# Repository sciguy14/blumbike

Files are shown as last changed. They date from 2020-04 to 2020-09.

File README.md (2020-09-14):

# BLUM.BIKE
This repo contains the code and documentation related to my blum.bike IOT bike trainer project. My instance of this project is publically accessible at [blum.bike](https://blum.bike), but you can use this code to deploy your own implementation.
  
Copyright 2020 [Jeremy Blum](https://www.jeremyblum.com), [Blum Idea Labs, LLC.](https://www.blumidealabs.com)  
This project is licensed under the MIT license (see LICENSE.md for details).

## Current Features
* Workout session starts automatically when you start biking.
* Live speed, heatrate, and resistance are shown on the webapp during a session.
* Summary of the last ride is shown when not in a session.
* If being accessed the same public-facing IP that is broadcasting the data, controls will be shown allowing you to control the resistance during a session.
* Resistance can be dynamically controlled using a stepper motor coupled into the dyno-adjustment leadscrew.
* Heartrate is captured using a Polar heartrate chest strap.

## Repo Organization
* [blumbike_hardware](blumbike_hardware/): This folder includes the schematics, datasheets, and mechanical design files necessary for building the bike hardware.
* [blumbike_particle_firmware](blumbike_photon_firmware/): These are firmware files for flashing to the Particle Photon that powers the bike electronics.
* [blumbike_web_app](blumbike_web_app/): This the Python-based web app that is deployed to a Heroku Dyno.

## System Design
blum.bike has two main components: some cloud-connected simple electronics mounted to stationary bike, and a web app running on a Heroku free-tier dyno. They are connected via the Particle Cloud (a service the accompanies the Particle Photon microcontroller used in this project).

### Key Bike Hardware
* A road bike mounted on a stationary bike stand ([Amazon Link](https://amzn.to/3ezBoth)). A piece of black tape is added to the dyno. Its rotation in front of the optical sensor is used to compute dyno RPM.
* A [3D printed arm](blumbike_hardware/mechanical/breadboard_holder/) for mounting a full-length breadboard to the rear of the bike dyno. This part snaps in place, and is fixed in place with a hex standoff that inserts into one of the bolts on the Dyno.
* A full-length breadboard with the following main elements (see the full schematic in the [blumbike_hardware/schematics](blumbike_hardware/schematics/) folder and relevant datasheets in the [blumbike_hardware/datasheets](blumbike_hardware/datasheets/) folder).
    * A Particle Photon ([Documentation](https://docs.particle.io/datasheets/wi-fi/photon-datasheet)) cloud-connected microcontroller.
    * A QRD1114 optical sensor for measuring dyno RPM.
    * A comparator/hysteresis circuit based on an OPA344 Op-Amp for cleaning up the RPM measurement.
    * A Polar wireless heart rate receiver. This is attached via a wire harness to put it close to the bike seat.
    * A Polar T34 Chest strap heart rate sensor ([Amazon Link](https://amzn.to/2RPv1s9)).
    * A Trinamic TMC2209 Stepper Driver breakout board for driving a stepper motor that adjusts dyno resistance ([Amazon Link](https://amzn.to/2YsIutj))
    * A L7805 Linear 5V regulator (plus bulk decoupling caps) for powering the logic elements from the 12V AC/DC wall adapter (12V is used for the Stepper Motor supply).
* A 12V, 1.5A AC/DC Wall adapter
* A NEMA-17 Stepper motor with a Planetary Gearbox ([Amazon Link](https://amzn.to/3emq3wr)) and 3D-printed adapter for controlling dyno resistance
* An endstop switch clipped onto the adjustable dyno with a 3D-printed bracket (so the stepper motor can home its resistance)

### Photon Firmware and Cloud
The Particle Photon runs some simple firmware that determines session start/stop time, heart rate, bike speed, etc. It publishes all the relevant data to the particle cloud once per second. The particle cloud is configred to fire a webhook to the python web app each time an update is received. A secret API key is inserted into the webhook contents, which is validated by the receiving web app.

### Python Web App Implementation
The web app is built as a python virtual env. It uses [Plotly Dash](https://dash.plotly.com/introduction) as the main mechanism for the UI and the graphs. It is deployed onto a [Heroku Free-Tier Dyno](https://www.heroku.com/pricing) and it leverages a [Heroku redis](https://elements.heroku.com/addons/heroku-redis) resource to maintain data for the duration of a session. To secure communication between the Particle cloud and the Heroku server, a matching API key is generated and stored in a Heroku environment variable for validating that the incoming webhook data from the Particle cloud is authentic. [Dash Bootstrap Components](https://dash-bootstrap-components.opensource.faculty.ai/) are used for the styling of the front-end.

## Instructions
This section is still a work in progress as I am still developing this project.
1. Fork this Repo to your own gitHub account and modify it as you desire.
2. 3D Print and assemble the mechanical elements. Build the circuit as described by the schematic. You will probably need to use a scope or a logic analyzer to get the alignment of the optical sensor working properly to generate consistent pulses on each dyno rotation.
3. Associate the Particle Photon to your Wi-Fi network and to your Particle Cloud account.
4. Use the Particle Dev IDE to flash the firmware onto the Photon via the cloud, or copy the firmware into their cloud IDE and flash it from there. Ensure that you see events streaming into the Particle Cloud interface for your device.
5. On the Particle Cloud Integration page, setup a new Webhook. Choose to create a custom template and populate it as follows (replacing the <> items accordingly):
    ```JSON
    {
        "event": "bike_data",
        "deviceID": "<YOUR_DEVICE_ID>",
        "url": "https://<YOUR_HEROKU_URL>/update",
        "requestType": "POST",
        "noDefaults": true,
        "rejectUnauthorized": true,
        "json": {
            "event": "{{{PARTICLE_EVENT_NAME}}}",
            "data": "{{{PARTICLE_EVENT_VALUE}}}",
            "apikey": "<YOUR_RANDOMLY_GENERATED_API_KEY>"
        }
    }
    ```  
    The API key can be whatever you want. You will just need to use the same key when you setup the heroku environment variables. We use this in the webapp to ensure that we only process incoming data with this secret API key attached.
6. Now, you need to create an access token associated with your particle.io account that can be used to sent authenicated commands to your particle photon. Install the [Particle Cli](https://docs.particle.io/tutorials/developer-tools/cli/)
7. Once the cli is installed launch your terminal and run `particle setup` to login, and then run `particle token create --never-expires`. This will add a token to your account that can be used the authenticate the app. The token will be printed to the console. Copy it somewhere for use in later steps.
8. Create a Heroku Account, and spin up a free-tier dyno.
9. Choose to "Deploy from GitHub" and connect it to your GitHub account. Point it at the repo that you forked to your account.
10. On the "Settings" page for the dyno, add the following "Config Vars":  
    `apikey` = `<YOUR_RANDOMLY_GENERATED_API_KEY>` - this is the same API key you configured in the JSON webhook above.  
    `PROJECT_PATH` = `blumbike_web_app` - this will make the Heroku automatic GitHub deployment look in the right subfolder of this repo for the application ([more info about this](https://stackoverflow.com/a/53221996)).  
    `SECRET_KEY` = `<ANY_RANDOM_KEY_YOU WANT>` - this is used for session management in the app. It is sepeerate from your api key and your access token.  
    `PARTICLE_TOKEN` = `<THE_PARTICLE_TOKEN_YOU_GENERATED_IN_THE_PARTICLE_CLI>` - this is the access token you generated above. The particle cloud will only approve the apps control request if this matches an allowed token.  
    `PARTICLE_ID` = <`THE_UNIQUE_ID_FOR_YOUR_PARTICLE`> - get this from the particle web console. It will match this format: `0123456789abcdef01234567` (24 hex digits)
11. Add a buildpack that will ensure the right subdirectory is used for automatic deployment. Add https://github.com/timanovsky/subdir-heroku-buildpack.git to the buildpack list and drag it to the top of the list (above python).
12. On the "Resources" page for your Dyno add a Heroku Redis instance. This should automatically add a "Config Var" with your `REDIS_URL`. This app will use this redis store to hold your data.
13. On the "Deploy" page, choose to deploy your master branch. Future deploys will happen automatically each time you push local changes to your upstream master branch.

## Doing Local Development
It's impractical to re-deploy to Heroku for every software change that you want to test. I recommend the following local development environment:  
I like using [PyCharm](https://www.jetbrains.com/pycharm/) for development of the Python web app, and I used [Particle Dev](https://docs.particle.io/tutorials/developer-tools/dev/) to write and deploy firmware to the Particle Photon.
  
[Ngrok](https://ngrok.com/) can be used to pipe the Photon webhooks to the localhost development server that you'll be running on your local machine. Create an account, and install it on your development machine. Once installed, launch the service with `ngrok http 8050`. This will give you a forwarding URL of the format `https://<UNIQUE ID>.ngrok.io`. You can also see this URL in your ngrok dashboard at [dashboard.ngrok.com](https://dashboard.ngrok.com/status/tunnels). Temporarily edit your Particle webhook event to use this URL instead of the heroku URL. So for example, you would cheange `https://my-app.herokuapp.com/update` to `https://abcde12345.ngrok.io/update`. You should be able to see the webhook requests come into this termainal window as soon as you point the Particle webhook at this address. You will see "502 Bad Gateway Errors" until you actually launch your local development server from PyCharm.
  
Create a new PyCharm project in the `blumbike_web_app` folder. Set up the Virtual Env using the requirements.txt file (PyCharm should prompt you to install the right things). Create a Run configuration pointed at app.py and using the Virtual Env interpreter. Add the following environment variables ([instructions](https://stackoverflow.com/questions/42708389/how-to-set-environment-variables-in-pycharm/42708480#42708480)):
* `mode` = `dev` - This will configure the server to run on local port 8050, which is what you used to setup ngrok.
* `apikey` = `<PUT_YOUR_API_KEY_HERE>` - This is the same apikey that you added to the particle webhook JSON message and to heroku.
* `REDIS_URL` = `<PUT_YOUR_REDIS_URL_HERE>` - You can use the same REDIS URL that is used by Heroku, or you can run a seperate development redis instance on your local machine and point at that.
* `SECRET_KEY` = `<PUT_YOUR_SECRET_KEY_HERE>` - This is the same secret key that you entered in heroku.
* `PARTICLE_TOKEN` = `<PUT_YOUR_PARTICLE_TOKEN_HERE>` - This is the same particle token, retrieved from the particle cli, that you added to the heroku env vars.
* `PARTICLE_ID` = <`THE_UNIQUE_ID_FOR_YOUR_PARTICLE`> - get this from the particle web console. It will match this format: `0123456789abcdef01234567` (24 hex digits)
  
Run the PyCharm configuration that you setup, and the ngrok instance should start showing "200 OK" responses. Visit [localhost:8050/](http://localhost:8050/) in your webbrowser to see your local instance of the web app. You can see more details about the webhooks coming into your machine via the ngrok inspection interface at [localhost:4040/inspect/http](localhost:4040/inspect/http).

## Other Useful References
The following are some use websites that I referenced while working on this project. You might find them useful as well:
* [Curing Comparator Instability with Hysteresis](https://www.analog.com/en/analog-dialogue/articles/curing-comparator-instability-with-hysteresis.html#)
* [Inverting Schmitt Trigger Calculator](https://www.random-science-tools.com/electronics/inverting-schmitt-trigger-calculator.htm)
* [Using an Op-amp as a Comparator](https://www.electronics-tutorials.ws/opamp/op-amp-comparator.html)
* [QRD1114 Optical Detector Hookup Guide](https://learn.sparkfun.com/tutorials/qrd1114-optical-detector-hookup-guide/all)
* [Particle Photon API Reference](https://docs.particle.io/reference/device-os/firmware/photon/#cloud-functions)
* [Plotly Dash Documentation](https://dash.plotly.com/dash-core-components)

_Disclaimers: As an Amazon Associate, I earn from qualifying purchases if you purchase items via Amazon.com links in this README. I also assume no liability if you manage to injure yourself while using a stationary bike._

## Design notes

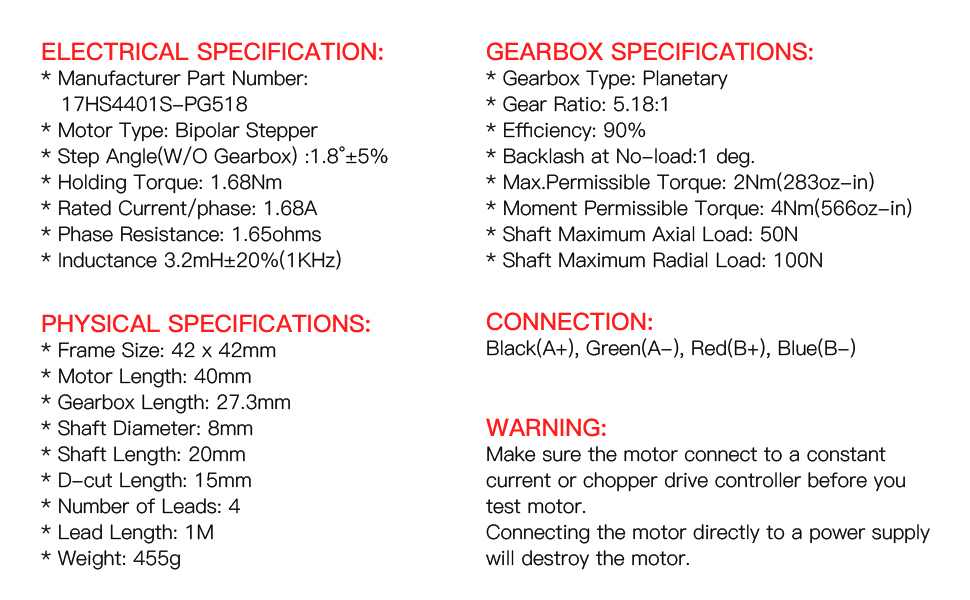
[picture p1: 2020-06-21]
blumbike_hardware/datasheets/Stepper-Motor_Specs.jpg

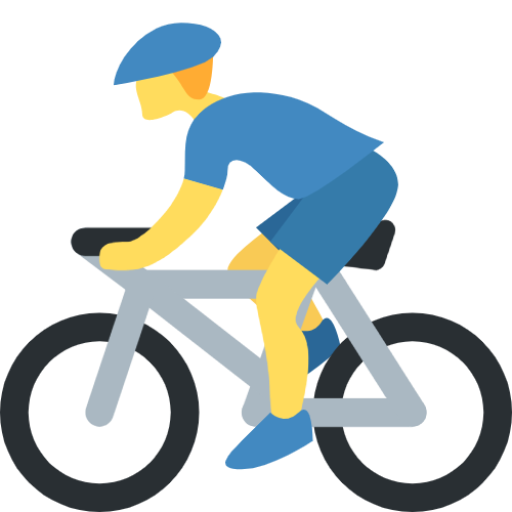
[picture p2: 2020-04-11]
blumbike_web_app/assets/android-chrome-512x512.png

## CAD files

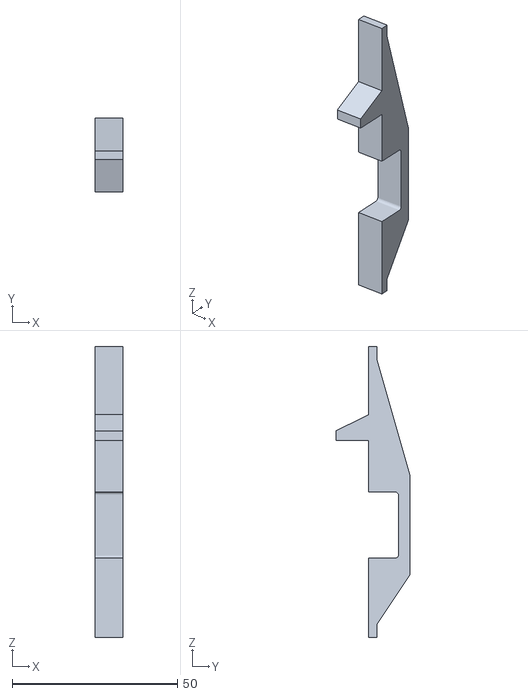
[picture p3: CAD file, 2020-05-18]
blumbike_hardware/mechanical/breadboard_holder/top_clip.stl
8.50 x 22.4 x 88.0

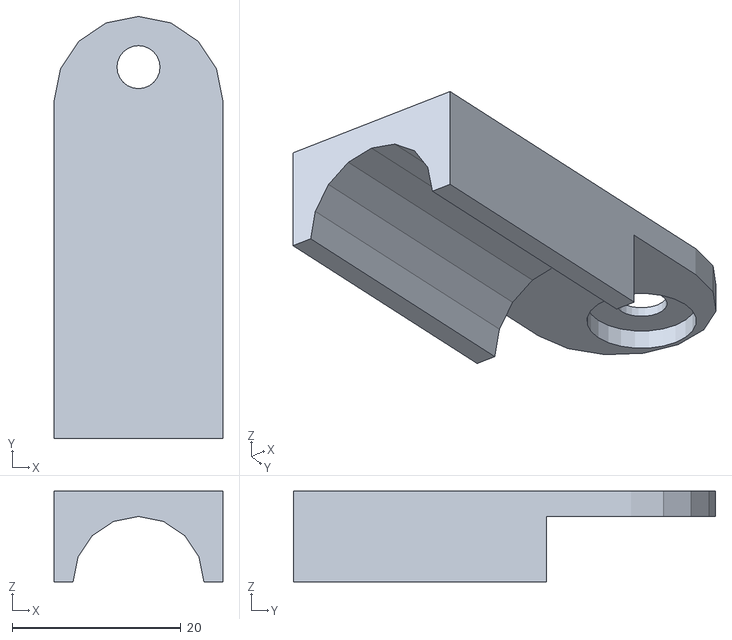
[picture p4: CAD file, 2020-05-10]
blumbike_hardware/mechanical/heartrate_sensor_holder/heartrate_sensor_holder.stl
20.0 x 50.0 x 10.7

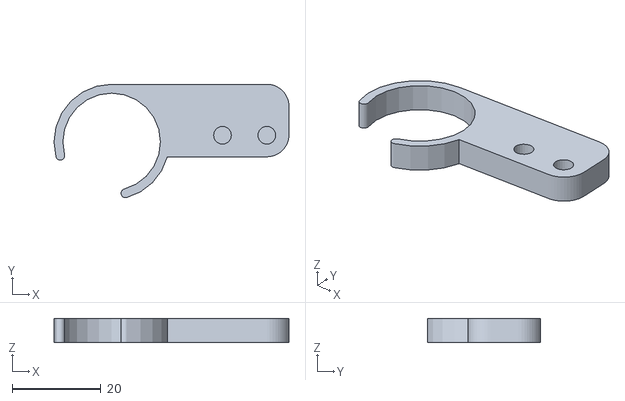
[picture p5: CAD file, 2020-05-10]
blumbike_hardware/mechanical/resistance_limit_switch_holder/resistance_limit_switch_holder.stl
53.0 x 25.6 x 5.50

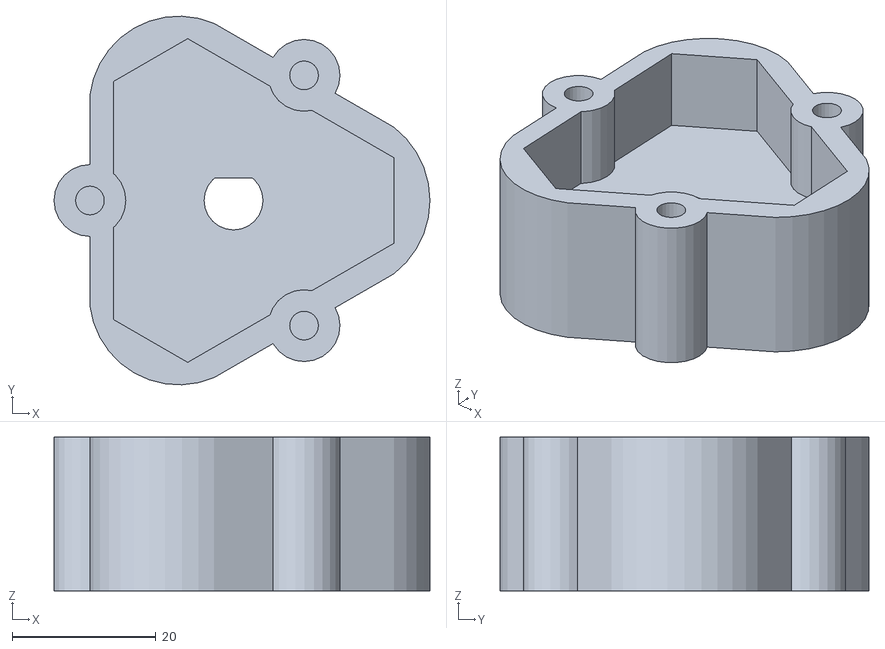
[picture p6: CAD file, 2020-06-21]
blumbike_hardware/mechanical/stepper_adapter/stepper_adapter_body.stl
52.4 x 51.3 x 21.4

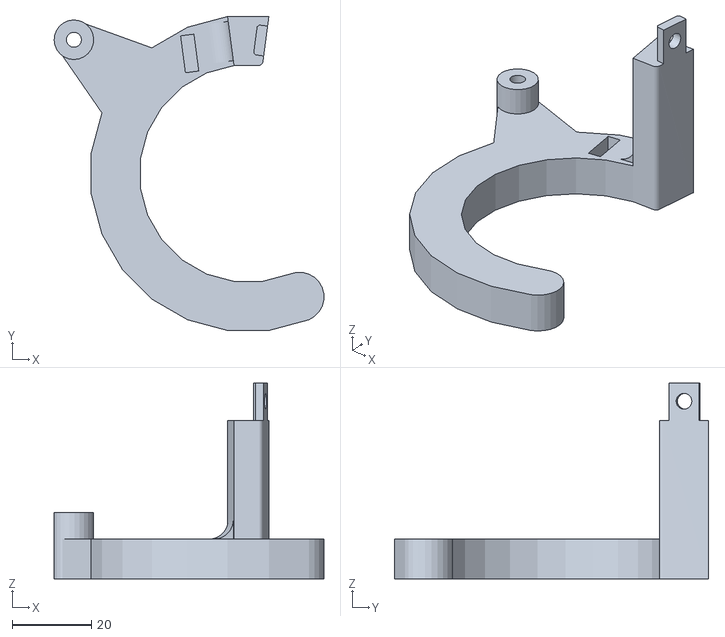
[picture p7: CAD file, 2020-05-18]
blumbike_hardware/mechanical/breadboard_holder/bottom_clip_right.stl
68.1 x 79.3 x 49.4

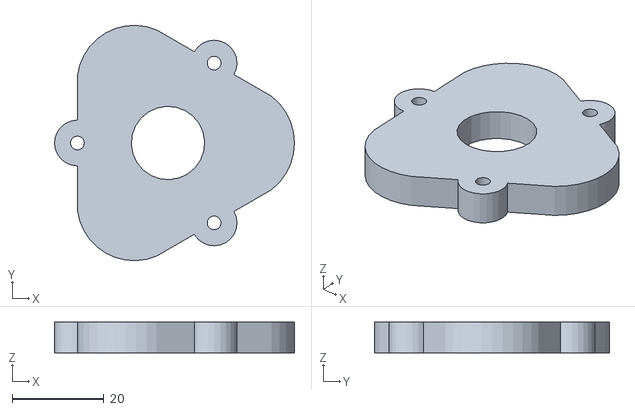
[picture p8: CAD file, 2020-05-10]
blumbike_hardware/mechanical/stepper_adapter/stepper_adapter_lid.stl
52.4 x 51.3 x 6.70

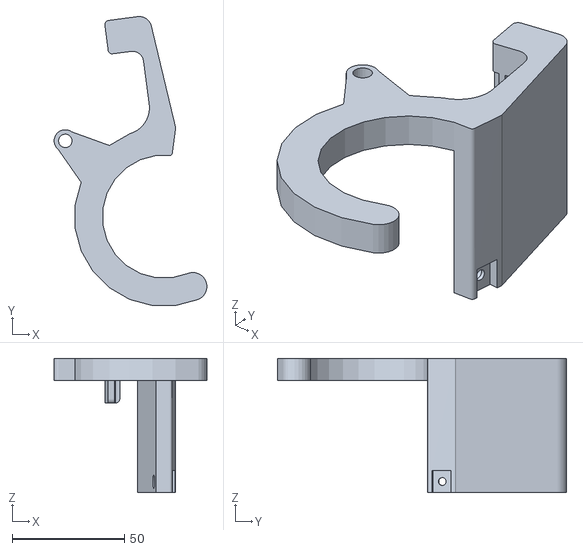
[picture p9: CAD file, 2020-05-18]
blumbike_hardware/mechanical/breadboard_holder/bottom_clip_left.stl
68.1 x 128.9 x 60.0

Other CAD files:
blumbike_hardware/mechanical/breadboard_holder/breadboard_holder.skp
blumbike_hardware/mechanical/heartrate_sensor_holder/heartrate_sensor_holder.skp
blumbike_hardware/mechanical/resistance_limit_switch_holder/resistance_limit_switch_holder.skp
blumbike_hardware/mechanical/stepper_adapter/stepper_adapter.skp

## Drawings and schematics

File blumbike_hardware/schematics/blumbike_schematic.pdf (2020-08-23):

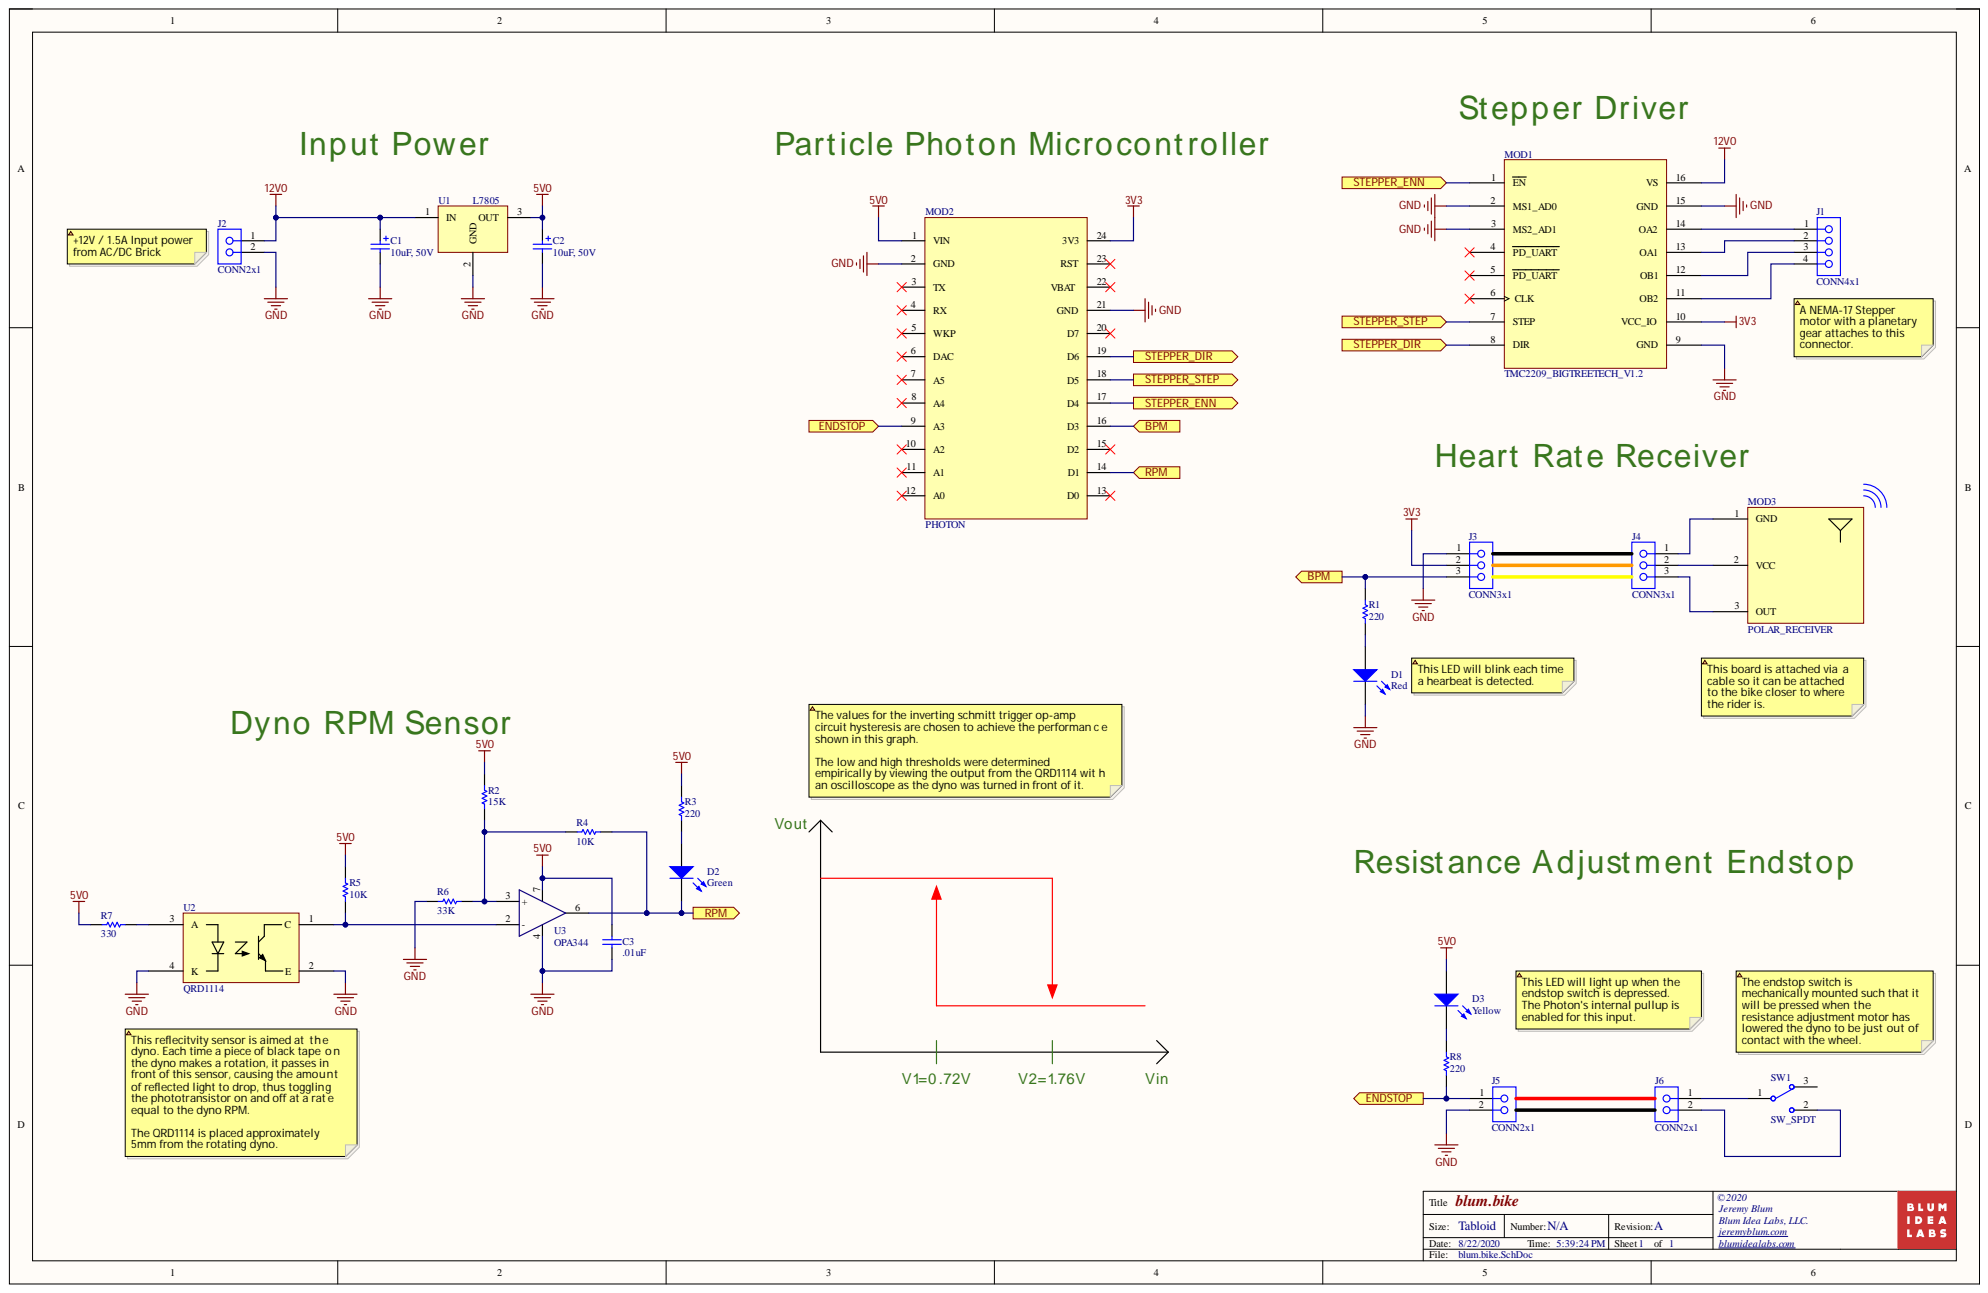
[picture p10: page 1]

+12V / 1.5A Input power from AC/DC Brick

A NEMA-17 Stepper
motor with a planetary gear attaches to this

GND 1

VCC 2

This LED will blink each time a hearbeat is detected.

This board is attached via a cable so it can be attached to the bike closer to where

The values for the inverting schmitt trigger op-amp circuit hysteresis are chosen to achieve the performance

shown in this graph.

The low and high thresholds were determined empirically by viewing the output from the QRD1114 with

an oscilloscope as the dyno was turned in front of it.

This LED will light up when the endstop switch is depressed.

The endstop switch is mechanically mounted such that it

The Photon's internal pullup is
enabled for this input.

will be pressed when the
resistance adjustment motor has lowered the dyno to be just out of contact with the wheel.

This reflecitvity sensor is aimed at the dyno. Each time a piece of black tape on

the dyno makes a rotation, it passes in front of this sensor, causing the amount

of reflected light to drop, thus toggling
the phototransistor on and off at a rate equal to the dyno RPM.

The QRD1114 is placed approximately 5mm from the rotating dyno.

blum.bike Title | © 2020 Jeremy Blum Blum Idea Labs, LLC. jeremyblum.com

Size: Tabloid | Number: N/A | Revision: A

Date: 8/22/2020 Time: 5:39:24 PM | | Sheet 1 of 1 | blumidealabs.com

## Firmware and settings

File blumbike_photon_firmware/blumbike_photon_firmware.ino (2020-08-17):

// blum.bike Photon Firmware
// Copyright 2020 Jeremy Blum, Blum Idea Labs, LLC.
// www.jeremyblum.com
// This code is licensed under MIT license (see LICENSE.md for details)

// Includes
#include "math.h"

// Define compiler replacements for Stepper motor direction
#define HIGHER_RESISTANCE LOW
#define LOWER_RESISTANCE HIGH

// Define compiler replacements for endstop start_session
#define PRESSED LOW
#define UNPRESSED HIGH

// Define Pin Constants
const int ENDSTOP_PIN       = A3; // The switch that triggers when the resistance adjuster stepper is at the end of its range
const int RPM_PIN           = D1; // The output of the inverting comparator w/ hysteresis for measuring bike speed
const int BPM_PIN           = D3; // The output pulses from the Heart rate BPM Polar receiver
const int ONBOARD_LED_PIN   = D7; // The onboard blue LED
const int STEPPER_ENN       = D4; // TMC2209 Stepper Driver Enable Pin (Active Low)
const int STEPPER_STEP      = D5; // TMC2209 Stepper Driver Step Pin
const int STEPPER_DIR       = D6; // TMC2209 Stepper Driver Direction Pin

// Configuration Constants
const unsigned int UPDATE_RATE_MS                               = 1000; // Update and send the new values every 1000 milliseconds (this should not be any lower than 1000)
const unsigned int BPM_INTERRUPTED_THRESHOLD                    = 2000; // If more than this many milliseconds have elapsed since the last BPM trigger, presume the sensor is not transmitting
const unsigned int SESSION_STARTED_SEQUENTIAL_NON_ZERO_READINGS = 2;    // A new session is triggered when this many non-zero RPM readings are found in a row
const unsigned int SESSION_ENDED_SEQUENTIAL_ZERO_READINGS       = 6;    // A session is ended when this many zero RPM readings are found in a row
const double RPM_MOVEMENT_THRESHOLD                             = 1.0;  // To address floating point errors, set this value as the movement threshold. Anything below this is effectively "zero" movement
const double ZERO_RESISTANCE_TURNS                              = 2.75; // The number of full output shaft turns the stepper motor must do to achieve the minimum resistance setting (just barely touching the wheel)
const double ROTATIONS_PER_RESISTANCE_STEP                      = 0.25; // Every 1/4th turn of the stepper motor output shaft is equal to one "resistance step"
const unsigned int DEFAULT_RESISTANCE                           = 3;    // This is the default starting session resistance
const unsigned int MAX_RESISTANCE                               = 10;   // This is the maximum resistance setting
const unsigned int MIN_RESISTANCE                               = 1;    // This is the minimum resistance setting

// Define Math Constants
const double BIKE_WHEEL_DIAMETER    = 27.0;            // inches
const double DYNO_WHEEL_DIAMETER    = 1.80;            // inches
const double PI                     = 3.14159265359;   // ratio
const double FEET_PER_MILE          = 5280.0;          // ratio
const double INCHES_PER_FOOT        = 12.0;            // ratio
const double MINUTES_PER_HOUR       = 60.0;            // ratio
const double SECONDS_PER_MINUTE     = 60.0;            // ratio
const double MILLIS_PER_SECOND      = 1000.0;          // ratio
const double STEPS_PER_REV_NO_GEAR  = 200.0;           // The NEMA-17 Stepper motor has 200 steps/rev
const double MICROSTEPPING          = 8.0;             // MS1 and MS2 are pulled down by default putting us in 1/8 Microstepping mode
const double GEAR_RATIO             = 5.18;            // The planetary gearbox for the motor is 5.18:1

// Computed Constants
const double BIKE_WHEEL_CIRCUMFERENCE_INCHES       = PI * BIKE_WHEEL_DIAMETER;                                          // inches
const double BIKE_WHEEL_CIRCUMFERENCE_FEET         = BIKE_WHEEL_CIRCUMFERENCE_INCHES / INCHES_PER_FOOT;                 // feet
const double BIKE_WHEEL_REVOLUTIONS_PER_MILE       = FEET_PER_MILE / BIKE_WHEEL_CIRCUMFERENCE_FEET;                     // revs / mile
const double DYNO_WHEEL_CIRCUMFERENCE_INCHES       = PI * DYNO_WHEEL_DIAMETER;                                          // inches
const double BIKE_DYNO_CIRCUMFERENCE_RATIO         = BIKE_WHEEL_CIRCUMFERENCE_INCHES / DYNO_WHEEL_CIRCUMFERENCE_INCHES; // rpm multiplier
const double STEPS_PER_REV                         = STEPS_PER_REV_NO_GEAR * GEAR_RATIO * MICROSTEPPING;                // The actual number of step pulses to go a full rotation of the output shaft

// Define Cloud Functions
int resistanceUp(String na);
int resistanceDown(String na);

// Global Variables
char ip[128];
bool in_session = false;
unsigned long resistance = 0;
unsigned long sequential_non_zero_readings = 0;
unsigned long sequential_zero_readings = 0;
unsigned long timestamp_seconds = 0;
double dyno_rpm = 0.0;
double bike_rpm = 0.0;
double bike_mph = 0.0;
double heart_bpm = 0.0;
unsigned long last_rpm_time = 0;
volatile unsigned long revs = 0;
volatile unsigned long last_beat_time = 0;
volatile unsigned long beat_time = 0;
volatile double interrupt_bpm = 0.0;

void setup(){
    // register the cloud functions
    Particle.function("resistance_up", resistanceUp);
    Particle.function("resistance_down", resistanceDown);

    // Set Pin Directions/Modes
    pinMode(ENDSTOP_PIN, INPUT_PULLUP);
    pinMode(RPM_PIN, INPUT);
    pinMode(BPM_PIN, INPUT);
    pinMode(ONBOARD_LED_PIN, OUTPUT);
    pinMode(STEPPER_ENN, OUTPUT);
    pinMode(STEPPER_STEP, OUTPUT);
    pinMode(STEPPER_DIR, OUTPUT);
    digitalWrite(STEPPER_ENN, HIGH);
    digitalWrite(ONBOARD_LED_PIN, LOW);

    // Get our Public IP address
    // On the Web-app we only allow resistance control if the request originates from the same IP
    Particle.subscribe("particle/device/ip", ip_handler, MY_DEVICES);
    Particle.publish("particle/device/ip", PRIVATE);

    // Home the Resistance Stepper
    homeStepper();

    // Adjust the stepper such that the resistance is set to the default starting level
    adjustResistanceAbsolute(DEFAULT_RESISTANCE);

    // Cloud Variables - We don't need these, since we publish the values every second, but it's still useful to have them
    Particle.variable("in_session", in_session);
    Particle.variable("resistance", resistance);
    Particle.variable("dyno_rpm", dyno_rpm);
    Particle.variable("bike_rpm", bike_rpm);
    Particle.variable("bike_mph", bike_mph);
    Particle.variable("heart_bpm", heart_bpm);

    // Notify the cloud that the bike has been turned on
    timestamp_seconds = Time.now(); // Get the current time
    String msg = "{\"t\": " + String(timestamp_seconds) + ", \"event\": \"powered_on\"}";
    Particle.publish("bike_data", msg, PRIVATE | WITH_ACK);

    // Initialize the last time values to something correct so it is ready for first use
    last_rpm_time = millis();
    last_beat_time = millis();

    // Attach pin change interrupts
    attachInterrupt(RPM_PIN, rpmInterrupt, FALLING);
    attachInterrupt(BPM_PIN, bpmInterrupt, RISING);
}

void loop() {
    // Update at the requested update rate
    // leverage some of this time to keep the update pulse LED on long enough to see
    delay(200);
    digitalWrite(ONBOARD_LED_PIN, LOW);
    delay(UPDATE_RATE_MS-200);

    // Get the current time
    timestamp_seconds = Time.now();

    // Disable interrupts while we process volatile data
    noInterrupts();

    // RPM tracking
    dyno_rpm =  SECONDS_PER_MINUTE*double(UPDATE_RATE_MS)/double(millis() - last_rpm_time)*double(revs); // Compute the RPMs of the Dyno
    last_rpm_time = millis(); // Reset the rpm clock
    revs = 0; // Reset the rpm counter

    //Manage the condition where heartrate is zero
    if (millis() - last_beat_time > BPM_INTERRUPTED_THRESHOLD) {
        heart_bpm = 0.0;
    } else {
        // Set Heartrate equal to he value of the volatile variable computed in the interrupt
        heart_bpm = interrupt_bpm;
    }

    // Interrupts can now trigger again since we are done with the volatile variable
    interrupts();

    // Compute the current bike speed regardless of whether we are currently in a session, so it is visible in the cloud variable
    bike_rpm = dyno_rpm / BIKE_DYNO_CIRCUMFERENCE_RATIO; // Compute the Bike wheel RPM from the Dyno RPM
    bike_mph = (bike_rpm / BIKE_WHEEL_REVOLUTIONS_PER_MILE) * MINUTES_PER_HOUR; // Convert RPM to MPH based on physical constants

    // Constuct a message with the info we care about and send it up to the cloud if we are currently in an active session
    if (in_session) {
        digitalWrite(ONBOARD_LED_PIN, HIGH);
        String msg = "{\"t\": " + String(timestamp_seconds) + ", \"event\": \"new_data\", \"bike_mph\": " + String(bike_mph) + ", \"resistance\": " + String(resistance) + ", \"heart_bpm\": " + String(heart_bpm) + "}";
        Particle.publish("bike_data", msg, PRIVATE | WITH_ACK);
    }

    // Get the current time again since above command could be blocking if cloud is unresponsive
    timestamp_seconds = Time.now();

    // If we are not currently in a session, look for movement to see if we should start one
    if (!in_session) {
        if (dyno_rpm >= RPM_MOVEMENT_THRESHOLD) {
            sequential_non_zero_readings = sequential_non_zero_readings + 1;
            if (sequential_non_zero_readings >= SESSION_STARTED_SEQUENTIAL_NON_ZERO_READINGS) {
                in_session = true;
                sequential_non_zero_readings = 0; // Reset variable so its ready for next time

                String msg = "{\"t\": " + String(timestamp_seconds) + ", \"event\": \"start_session\", \"ip\": \"" + String(ip) + "\"}";
                Particle.publish("bike_data", msg, PRIVATE | WITH_ACK);
            }
        } else {
            sequential_non_zero_readings = 0; // Reset variable if readings are not sequential
        }
    // If we are currently in a session, check to see if movement has stopped, so we can end the session
    } else if (in_session) {
        if (dyno_rpm < RPM_MOVEMENT_THRESHOLD) {
            sequential_zero_readings = sequential_zero_readings + 1;
            if (sequential_zero_readings >= SESSION_ENDED_SEQUENTIAL_ZERO_READINGS) {
                in_session = false;
                sequential_zero_readings = 0; // Reset variable so its ready for next time

                String msg = "{\"t\": " + String(timestamp_seconds) + ", \"event\": \"end_session\"}";
                Particle.publish("bike_data", msg, PRIVATE | WITH_ACK);
            }
        } else {
            sequential_zero_readings = 0; // Reset variable if readings are not sequential
        }
    }
}

// This interrupt triggers every time the dyno does a rotation
void rpmInterrupt()
{
    revs = revs + 1;
}

// This interrupt triggers everytime we receive a heartbeat signal
void bpmInterrupt()
{
    beat_time = millis();
    interrupt_bpm = SECONDS_PER_MINUTE/((beat_time-last_beat_time)/MILLIS_PER_SECOND); // Compute the BPM from the heartrate sensor
    last_beat_time = beat_time; // Reset the beat timer
}

void homeStepper()
{
    // If the endstop pin is already pressed, we back off until it isn't and then rehome so we are as consistent as possible
    if (digitalRead(ENDSTOP_PIN) == PRESSED)
    {
        while (digitalRead(ENDSTOP_PIN) == PRESSED)
        {
            move(HIGHER_RESISTANCE, 0.01); // Raise a little bit at a time
        }
        move(HIGHER_RESISTANCE, 0.25); // Raise another quarter output shaft turn
        delay(100);
    }

    // Move twoards the endstop until it is pressed
    while (digitalRead(ENDSTOP_PIN) == UNPRESSED)
    {
        move(LOWER_RESISTANCE, 0.01); // Lower a little bit at a time
    }
    // The Stepper should now be "homed" to the lowest position with the endstop switch depressed

    delay(1000);

    // Raise to the zero resistance point
    move(HIGHER_RESISTANCE, ZERO_RESISTANCE_TURNS);
    resistance = 0;

    delay(1000);
}

// Functions for Adjusting the Dyno resistance
void adjustResistanceRelative(int levels)
{
    // The endstop should not be pressed unless we fell down a bunch since homing
    if (digitalRead(ENDSTOP_PIN) == PRESSED) homeStepper();

    // Bound us to the min/max
    if (resistance + levels > MAX_RESISTANCE) levels = MAX_RESISTANCE - resistance;
    if (resistance + levels < MIN_RESISTANCE) levels = MIN_RESISTANCE - resistance;

    // Move the Motor
    bool dir = LOWER_RESISTANCE;
    if (levels > 0) dir = HIGHER_RESISTANCE;
    move(dir, double(levels)*ROTATIONS_PER_RESISTANCE_STEP);
    resistance = resistance + levels;
}
void adjustResistanceAbsolute(unsigned int level)
{
    adjustResistanceRelative(level-resistance);
}

// Move the stepper Motor
// Motor is kept disabled when not moving
// This function is blocking
// dir = Direction of rotation
// rotations = Number of output shaft rotations
void move(bool dir, double rotations)
{
    //Set direction and enable motor
    digitalWrite(STEPPER_DIR, dir);
    digitalWrite(STEPPER_ENN, LOW);

    double steps = fabs(rotations) * STEPS_PER_REV;
    double i = 0.0;
    while (i < steps)
    {
        digitalWrite(STEPPER_STEP, HIGH);
        delayMicroseconds(75); // I experienced FreeRTOS timer issues if making this number too large (more than ~500)
        digitalWrite(STEPPER_STEP, LOW);
        delayMicroseconds(75);
        i = i + 1.0;

    }
    // Disable Motor
    digitalWrite(STEPPER_ENN, HIGH);
}

// Cloud functions that are called upon a matching POST request
int resistanceUp(String na)
{
    adjustResistanceRelative(1);
    return resistance;
}
int resistanceDown(String na)
{
    adjustResistanceRelative(-1);
    return resistance;
}


void ip_handler(const char *topic, const char *data) {
    strncpy(ip, (char *) data, 128);
}

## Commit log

2020-04-11 First commit based on Dash sample Dashboard
    [spc_data.csv]
2020-04-12 Now functionally receiving and plotting realtime data
    [spc_data.csv]
2020-04-12 Now using Redis a value store for session data instead of global vars which obviously won't work with multiple threads managing the webserver
2020-04-18 Reorganized Everything!
    Fleshed out the README a lot more.
    Added the MIT License.
    Added the Photon Firmware to this repo.
    Organized supporting documentation.
    Reconfigured Heroku to (hopefully) deploy from a subdirectory in here.
    [breadboard_holder.skp, breadboard_holder.stl]
2020-04-19 Improved Session Handling
    Photon now sends session start/stop updates based on bike activity.
    Bike stats are not sent when there is not a currently active session.
    Fixed some typos in the readme.
    Made the firmware a little more readable.
    Photon on-board LED blinks for each bike stat transmission.
    [blumbike_photon_firmware.ino]
2020-04-19 Improved Session Data in web app
    Now differentiates between a currently active session, and the info from a previous session.
    Shows stats from the previous session (average and max speed/heartrate).
2020-04-20 Properly track SEQUENTIAL Non-Zero/Zero RPM readings from bike to start/stop session
2020-05-10 Revamped all the 3D printed mechanical parts.
    Added mounting fixture for heartrate antenna.
    Made the Breadboard holder more secure.
    Added a clip to holder the resistance-adjuster endstop switch.
    Created a stepper motor adapter to enable a stepper motor to drive the resistance leadscrew.
    [bottom_clip_left.stl, bottom_clip_right.stl, breadboard_holder.skp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]
2020-05-10 Added Stepper Stabilizer for Resistance Adjustment mechanism
    [stepper_stabilizer.skp, stepper_stabilizer.stl]
2020-05-18 Made major improvements to the rigidity and repeatability of the breadboard holder.
    [bottom_clip_left.stl, bottom_clip_right.stl, breadboard_holder.skp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]
2020-05-18 Stepper Motor Home and Cloud Resistance Control now enabled in firmware
2020-06-21 Moved to a beefier stepper motor with an integrated gearbox.
    New adapter for handling 8mm motor shaft.
    New bracket for holding stepper motor in place.
    H-Bridge replaced with Trinamic driver board.
    Fixed a gitignore issue
    [stepper_adapter.skp, stepper_adapter_body.stl, stepper_stabilizer.skp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]
2020-08-10 Use session to track client IP and authorize control panel
2020-08-10 undo IP address printout for debuging heroku
2020-08-11 Added Resistance Plotting to Dashboard and fixed resistance-down control
    [blumbike_photon_firmware.ino]
2020-08-12 Control Panel Resistance Buttons should fire properly now (not connected to API yet)
2020-08-17 Support for controlling bike resistance now functional within the app
2020-08-17 release focus on buttons
2020-08-22 Updated button styling to improve mobile experience
2020-08-23 Add schematic showing how the hardware is setup.
2020-09-13 Remove unused stepper stabilizer 3D print
    [stepper_stabilizer.skp, stepper_stabilizer.stl, stepper_stabilizer_foot.stl]
